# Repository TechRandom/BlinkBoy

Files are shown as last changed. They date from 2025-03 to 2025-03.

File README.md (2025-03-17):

# BlinkBoy



The Blink Boy is an Open Source Handheld built around the ESP32-S3 micro-controller. You can create your own games and apps in the Arduino IDE making this a great project for beginner programmers. The Custom PCB can be modified in any way so you can practice your hardware design skills.

YouTube Video: 

Schematic:


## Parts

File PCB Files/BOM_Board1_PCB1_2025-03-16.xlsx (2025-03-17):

No. | Quantity | Comment | Designator | Footprint | Value | Manufacturer Part | Manufacturer | Supplier Part | Supplier
1 | 3 | K2-1157SP-I4SW-01 | BAT,BOOT,RESET | SW-SMD_4P-L6.2-W6.2-P4.50-LS8.6 |  | K2-1157SP-I4SW-01 | 韩国韩荣 | C2909692 | LCSC
2 | 4 | 10uF | C1,C4,C13,C14 | C0402 | 10uF
3 | 4 | 0.1uF | C2,C15,C16,C17 | C0402 | 0.1uF
4 | 1 | 100nF | C3 | C0402 | 100nF
5 | 1 | 10nF | C5 | C0402 | 10nF
6 | 1 | 1uF | C6 | C0402 | 1uF
7 | 3 | 0.1uF | C10,C11,C12 | C0402
8 | 1 | S2B-ZR-3.4(LF)(SN) | CN1 | CONN-TH_S2B-ZR-3.4-LF-SN |  | S2B-ZR-3.4(LF)(SN) | JST | C160729 | LCSC
9 | 1 | S2M | D1 | SMA_L4.4-W2.8-LS5.4-RD |  | S2M | MDD(辰达半导体) | C18905 | LCSC
10 | 1 | LED_0402-R | LED1 | LED0402-RD_YELLOW
11 | 1 | LED_0402-G | LED2 | LED0402-RD_YELLOW
12 | 4 | LED_0402-B | LED3,LED4,LED5,LED6 | LED0402-RD_YELLOW
13 | 121 | XL-5050RGBC-WS2812B | LED38,LED39,LED40,LED41,LED42,LED43,LED44,LED45,LED46,LED47,LED48,LED49,LED50,LED51,LED52,LED53,LED54,LED55,LED56,LED57,LED58,LED59,LED60,LED61,LED62,LED63,LED64,LED65,LED66,LED67,LED68,LED69,LED70,LED71,LED72,LED73,LED74,LED75,LED76,LED77,LED78,LED79,LED80,LED81,LED82,LED83,LED84,LED85,LED86,LED87,LED88,LED89,LED90,LED91,LED92,LED93,LED94,LED95,LED96,LED97,LED98,LED99,LED100,LED101,LED102,LED103,LED104,LED105,LED106,LED107,LED108,LED109,LED110,LED111,LED112,LED113,LED114,LED115,LED116,LED117,LED118,LED119,LED120,LED121,LED122,LED123,LED124,LED125,LED126,LED127,LED128,LED129,LED130,LED131,LED132,LED133,LED134,LED135,LED136,LED137,LED138,LED139,LED140,LED141,LED142,LED143,LED144,LED145,LED146,LED147,LED148,LED149,LED150,LED151,LED152,LED153,LED154,LED155,LED156,LED157,LED158 | LED-SMD_4P-L5.0-W5.0-BL_XL-5050RGBC |  | XL-5050RGBC-WS2812B | XINGLIGHT(成兴光) | C2843785 | LCSC
14 | 1 | SI2307 | Q1 | SOT-23-3_L2.9-W1.3-P0.95-LS2.4-BR |  | SI2307 | PAKER(派克微) | C5278890 | LCSC
15 | 3 | 1k | R2,R6,R7 | R0402
16 | 9 | 10K | R3,R9,R12,R13,R14,R16,R19,R20,R21 | R0402 | 10K
17 | 2 | 5.1k | R4,R5 | R0402 | 5.1k
18 | 2 | 1K | R8,R11 | R0402 | 1K
19 | 1 | 2K | R10 | R0402 | 2K
20 | 2 | 100K | R17,R18 | R0402 | 100K
21 | 1 | EC12D1524403 | SW2 | SW-TH_EC12D1524403 |  | EC12D1524403 | ALPSALPINE(阿尔卑斯阿尔派) | C112349 | LCSC
22 | 1 | 2.4GHz | U1 | BULETM-SMD_ESP32-S3-MINI-1-N8 | 2.4GHz | ESP32-S3-MINI-1-N8 | ESPRESSIF(乐鑫) | C2913206 | LCSC
23 | 1 | TP4056 | U2 | ESOP-8_L4.9-W3.9-P1.27-LS6.0-BL-EP |  | TP4056 | UMW(友台半导体) | C725790 | LCSC
24 | 1 | AP2112K-3.3TRG1 | U3 | SOT-25-5_L2.9-W1.6-P0.95-LS2.8-BL |  | AP2112K-3.3TRG1 | DIODES(美台) | C51118 | LCSC
25 | 1 | HX SS12D10G3-WJ | U4 | SW-TH_3P-P4.80_HX-SS12D10G3-WJ |  | HX SS12D10G3-WJ | hanxia(韩下) | C19189122 | LCSC
26 | 1 | TYPE-C-31-M-12 | USBC1 | USB-C_SMD-TYPE-C-31-M-12 |  | TYPE-C-31-M-12 | 韩国韩荣 | C165948 | LCSC

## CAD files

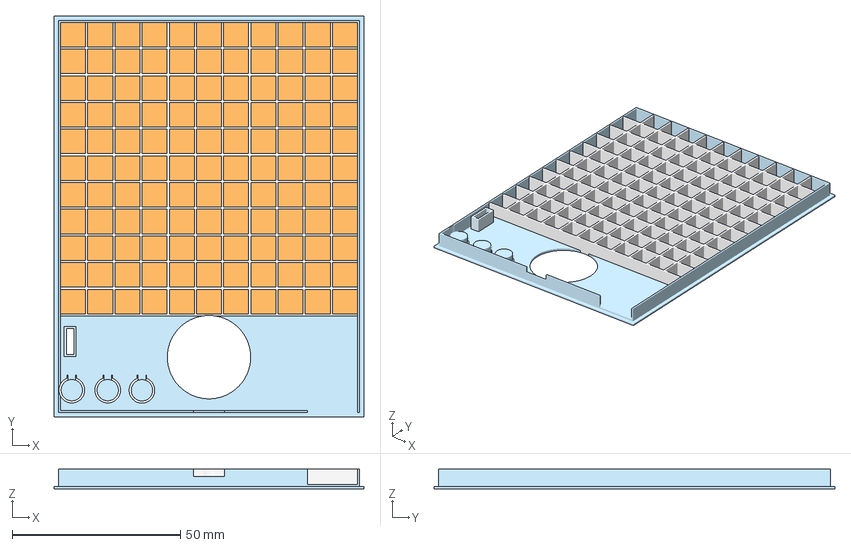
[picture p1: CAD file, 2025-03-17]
3D Print Files/BlinkBoyScreen.3mf
92.1 x 119.1 x 5.84 mm

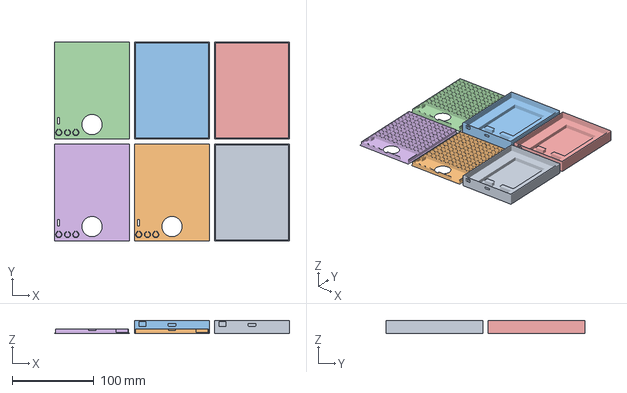
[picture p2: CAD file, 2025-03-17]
3D Print Files/BlinkBoyCase.3mf
288.2 x 244.3 x 16.5 mm
BlinkBoyCase x 3
BlinkBoyScreen x 3

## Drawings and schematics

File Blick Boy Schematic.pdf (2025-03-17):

IO48 30 IO35 31 IO36 32 IO37 33 IO38 34 IO39 35 IO40 36 IO41 37 IO42 38 TXD0 39 RXD0 40 IO45 41 GND 42 GND 43 IO46 44 EN 45 GND 46 GND 47 GND 48 GND 49 GND 50 GND 51 GND 52 GND 53 GND 54 GND 55 GND 56 GND 57 GND 58 GND 59 GND 60 GND

# ESP32-S3 MINI

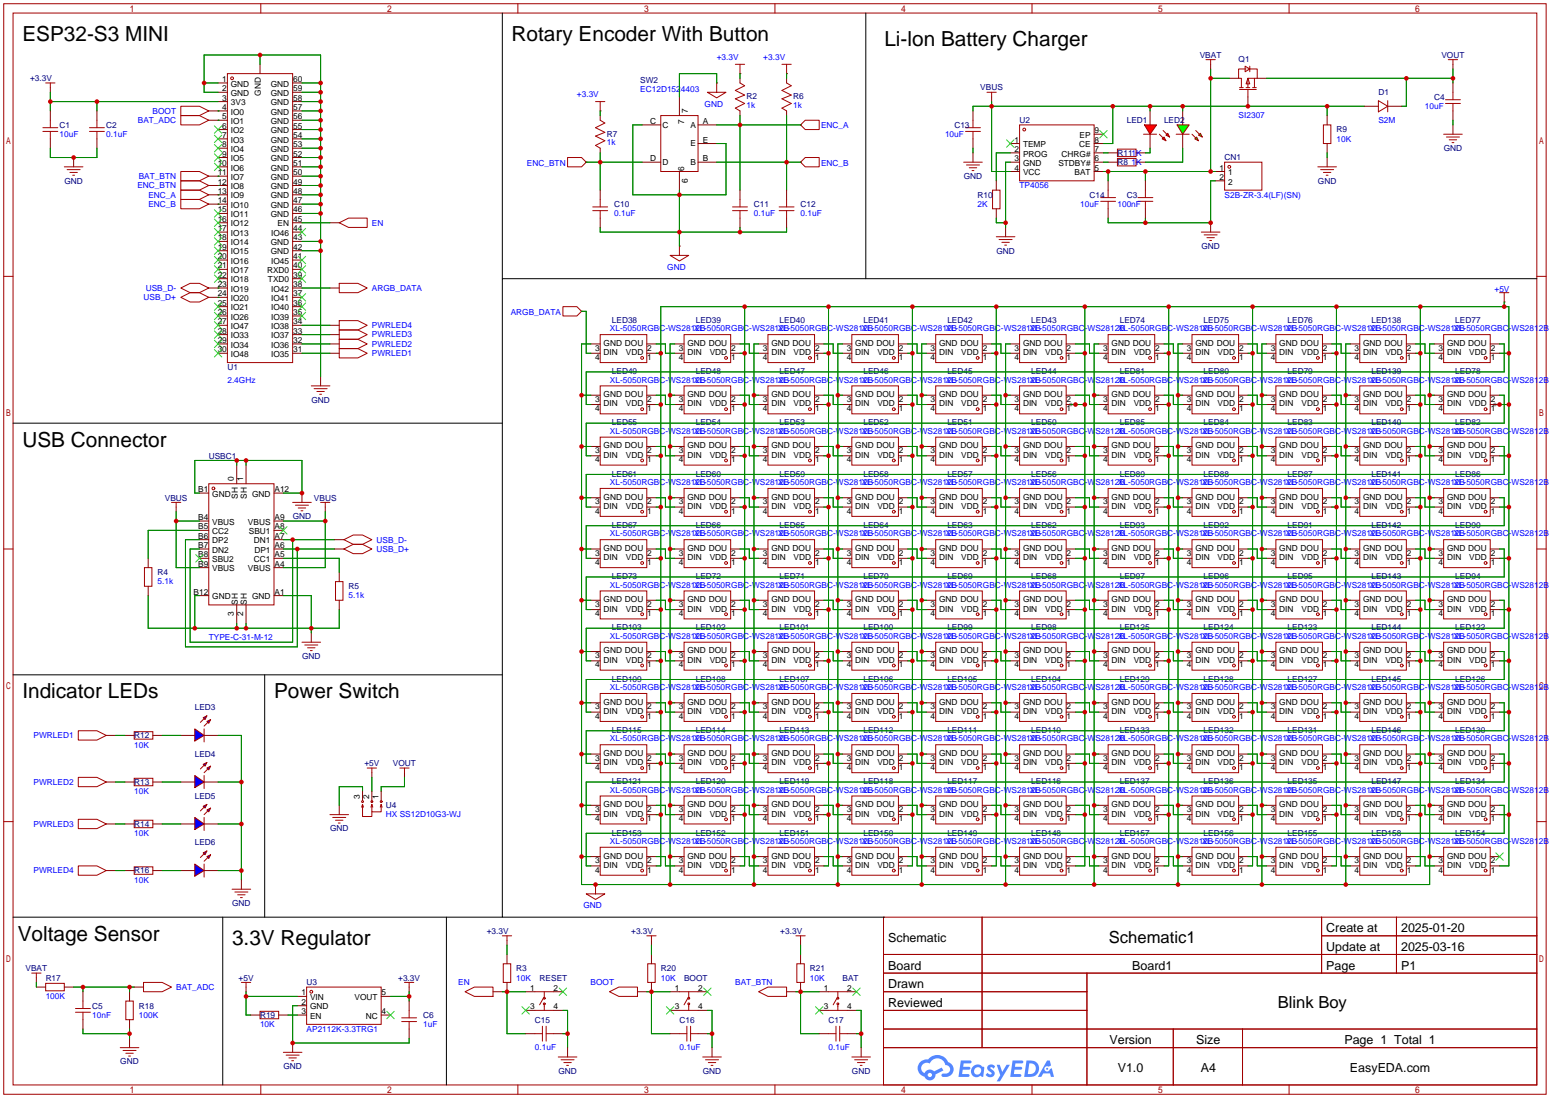
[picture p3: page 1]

Schematic | Schematic1 | Create at | 2025-01-20

Update at | 2025-03-16

Board | Board1 | Page | P1
Drawn | | Blink Boy
Reviewed

Version | Size | Page 1 Total 1
V1.0 | A4 | EasyEDA.com

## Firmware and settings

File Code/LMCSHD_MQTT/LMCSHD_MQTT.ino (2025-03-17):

#include <ESP8266WiFi.h>
#include <PubSubClient.h>

// WiFi and MQTT server settings
const char* ssid = "YOUR_SSID";
const char* password = "YOUR_PASSWORD";
const char* mqtt_server = "YOUR_MQTT_BORKER_IP";

// LED Matrix settings
const int WIDTH = 11;
const int HEIGHT = 11;
const int DATA_SIZE = WIDTH * HEIGHT * 3;
uint8_t frameData[DATA_SIZE];
char hexString[DATA_SIZE * 2 + 1] = {0}; // Each byte is represented by 2 hex characters

WiFiClient espClient;
PubSubClient client(espClient);

void setup() {
  Serial.begin(115200);
  setup_wifi();
  client.setServer(mqtt_server, 1883);
  client.setBufferSize(1024);
  client.setCallback(Ack);
  client.subscribe("cast/ack");
}

void setup_wifi() {
  delay(10);

  WiFi.begin(ssid, password);

  while (WiFi.status() != WL_CONNECTED) {
    delay(500);
  }
}

void Ack(char* topic, byte* payload, unsigned int length){
  Serial.write(0x06); // Acknowledge
}

void reconnect() {
  while (!client.connected()) {
    String clientId = "WemosD1Mini-";
    clientId += String(random(0xffff), HEX);

    if (client.connect(clientId.c_str())) {
    } else {
      delay(5000);
    }
  }
  client.subscribe("cast/ack");
}

void loop() {
  if (WiFi.status() != WL_CONNECTED) {
    setup_wifi();
  }
  if (!client.connected()) {
    reconnect();
  }
  client.loop();
  if (Serial.available()){
    switch (Serial.read()) {
      case 0x05: // Request for matrix definition
        Serial.println(WIDTH);
        Serial.println(HEIGHT);
        break;

      case 0x41: // 24bpp frame data
        char* buffer = (char*) frameData;
        Serial.readBytes(buffer, DATA_SIZE);
        client.publish("lmcshd/data", frameData, DATA_SIZE);
        break;
    }
  }
}

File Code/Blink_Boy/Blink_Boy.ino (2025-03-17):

#include "app.h"
#include "text.h"
#include "snakes.h"
#include "remote.h"
#include "cast.h"
#include <FastLED.h>
#include <WiFi.h>
#include <PubSubClient.h>

#define DATA_PIN 42
#define ENCODER_A 9
#define ENCODER_B 10
#define BATTERY_PIN 1
#define BATTERY_BUTTON_PIN 7
#define LED1 35
#define LED2 36
#define LED3 37
#define LED4 38

CRGB leds[NUM_LEDS];

TaskHandle_t Task1;
TaskHandle_t Task2;

volatile int encoderPosition = 0;
volatile bool encoderChanged = false;
int buttonState = HIGH;
int lastButtonState = HIGH;

int mode = 0;

const char* ssid = "YOUR_WIFI";
const char* password = "YOUR_PASSWORD";
const char* mqtt_server = "YOUR_MQTT_BROKER_IP";

WiFiClient espClient;
PubSubClient client(espClient);

QueueHandle_t xQueue;

// Emcoder Interrupt Handler
void IRAM_ATTR handleEncoderA() {
  if (digitalRead(ENCODER_A) == HIGH) {
    if (digitalRead(ENCODER_B) == LOW) {
      encoderPosition++;
    } else {
      encoderPosition--;
    }
  } else {
    if (digitalRead(ENCODER_B) == LOW) {
      encoderPosition--;
    } else {
      encoderPosition++;
    }
  }
  encoderChanged = true;
}

void setup_wifi() {
  delay(10);
  WiFi.begin(ssid, password);
  
  while (WiFi.status() != WL_CONNECTED) {
    delay(500);
  }
}

void reconnect() {
  while (!client.connected()) {
    String clientId = "ESP32-";
    clientId += String(random(0xffff), HEX);

    if (client.connect(clientId.c_str())) {
    } else {
      delay(5000);
    }
  }
}

void setup() {
  Serial.begin(115200);
  FastLED.addLeds<WS2812, DATA_PIN, GRB>(leds, NUM_LEDS);
  FastLED.setBrightness(BRIGHTNESS);
  pinMode(ENCODER_A, INPUT);
  pinMode(ENCODER_B, INPUT);
  pinMode(BUTTON_PIN, INPUT_PULLUP);
  pinMode(BATTERY_PIN, INPUT);
  pinMode(BATTERY_BUTTON_PIN, INPUT_PULLUP);
  pinMode(LED1, OUTPUT);
  pinMode(LED2, OUTPUT);
  pinMode(LED3, OUTPUT);
  pinMode(LED4, OUTPUT);

  attachInterrupt(digitalPinToInterrupt(ENCODER_A), handleEncoderA, CHANGE);

  setup_wifi();
  client.setServer(mqtt_server, 1883);

  xTaskCreatePinnedToCore(
    Task1code, /* Task function. */
    "Task1",   /* name of task. */
    10000,     /* Stack size of task */
    NULL,      /* parameter of the task */
    1,         /* priority of the task */
    &Task1,    /* Task handle to keep track of created task */
    0);        /* pin task to core 0 */

  xTaskCreatePinnedToCore(
    Task2code, /* Task function. */
    "Task2",   /* name of task. */
    10000,     /* Stack size of task */
    NULL,      /* parameter of the task */
    1,         /* priority of the task */
    &Task2,    /* Task handle to keep track of created task */
    1);        /* pin task to core 1 */
}

void loop() {
  // Empty. Tasks are running on different cores.
}

void Task1code(void * pvParameters) {
  for (;;) {
    if (!client.connected()) {
      reconnect();
    }
    client.loop();

    int batteryButtonState = digitalRead(BATTERY_BUTTON_PIN);
    if (batteryButtonState == LOW) {
      showBatteryLevel();
      delay(3000); // Show battery level for 3 seconds
      clearBatteryLEDs();
    }
    delay(100);
  }
}

void Task2code(void * pvParameters) {
  textColor = CRGB::DarkViolet;
  startScrollText("REMOTE", TEXT_SPEED);
  for (;;) {
    mainMenu();
  }
}

void showBatteryLevel() {
  int batteryLevel = analogRead(BATTERY_PIN);
  int level = map(batteryLevel, 1600, 2400, 0, 4); // Assuming 3.0V is 0% and 4.2V is 100%
  Serial.println(batteryLevel);
  digitalWrite(LED1, level > 0 ? HIGH : LOW);
  digitalWrite(LED2, level > 1 ? HIGH : LOW);
  digitalWrite(LED3, level > 2 ? HIGH : LOW);
  digitalWrite(LED4, level > 3 ? HIGH : LOW);
}

void clearBatteryLEDs() {
  digitalWrite(LED1, LOW);
  digitalWrite(LED2, LOW);
  digitalWrite(LED3, LOW);
  digitalWrite(LED4, LOW);
}

void mainMenu(){
  if (encoderChanged) {
    encoderChanged = false;
    mode = encoderPosition % NUM_MODES;
    if (mode < 0) mode += NUM_MODES;
    switch (mode) {
      case 0:
        textColor = CRGB::DarkViolet;
        startScrollText("REMOTE", TEXT_SPEED);
        break;
      case 1:
        textColor = CRGB::ForestGreen;
        startScrollText("SNAKES", TEXT_SPEED);
        break;
      case 2:
        textColor = CRGB::MediumSlateBlue;
        startScrollText("CAST", TEXT_SPEED);
        break;
      default:
        break;
    }
  }
  updateScrollText(); // Update the scrolling text
  FastLED.show();

  buttonState = digitalRead(BUTTON_PIN);
  if (buttonState == LOW && lastButtonState == HIGH) {
    lastButtonState = buttonState;
    delay(10);
    switch (mode) {
      case 0:
        startRemote();
        break;
      case 1:
        startSnakes();
        encoderChanged = true;
        break;
      case 2:
        startCast();
        break;
      default:
        break;
    }
  }
  lastButtonState = buttonState;
  delay(10);
}
